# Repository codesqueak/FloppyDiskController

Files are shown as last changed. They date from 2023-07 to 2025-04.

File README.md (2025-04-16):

# Floppy Disk Controller Version 2.2.1

Nascom / Gemini / 80-Bus 1793 Floppy Disk Controller

## Introduction

This card has been designed to be a functional replacement for the Nascom Floppy Disk Controller.  It is fully compatible with the existing NAS-DOS software

The card is a completely new implementation of the design with a number of improvements over the original:

*	Completely new track layout
*	All components are readily available from commercial component suppliers (..and eBay!)
*	Switches are fitted to standard  DIL sockets
*	Copious test points
* Full documentation

For full documentation, see the [pdf here](FDC.pdf).

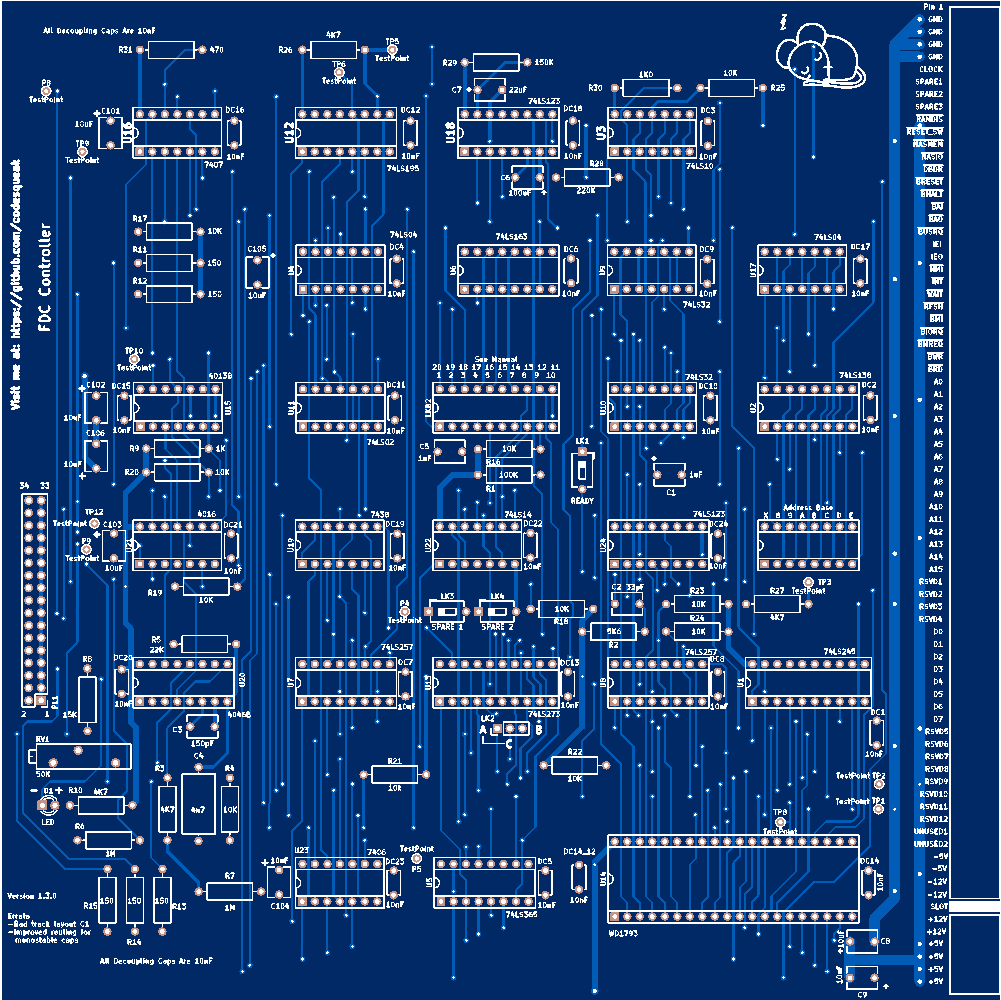
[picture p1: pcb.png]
PCB From JLCPCB
 

  Built PCB

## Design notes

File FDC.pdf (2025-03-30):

1793 Floppy Disk Controller Card

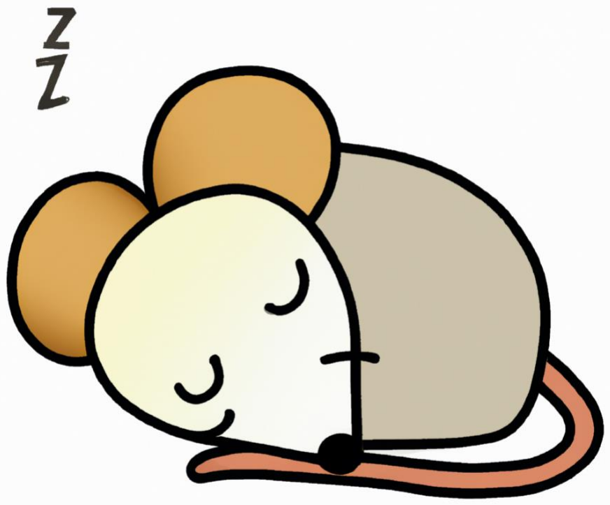
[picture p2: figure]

Issue 2.2.0 | Page 1 | 30-Mar-2025

## NAS-GEM-80 FDC CARD

### Instruction Manual & Functional Description

Issue 2.2.0 | Page 2 | 30-Mar-2025

## Contents

Issue 2.2.0 | Page 3 | 30-Mar-2025

## 1 Introduction

This card has been designed to be a form, fit and function replacement for the Nascom Floppy Disk

Controller, which is proving to be a very difficult item to source for the Nascom / Gemini retro

community.

The card has been tested against original Teac FD-50E/F drives without observed issues under NAS-

DOS 1.4

Further testing with CP/M and PolyDos is planned

Note: The card is designed to handle 5.25-inch drives. Support for 8-inch drives has been removed

(Did anyone ever use this?)

Issue 2.2.0 | Page 4 | 30-Mar-2025

## 2 Components

Reference | Value | Qty
C1 | 1uF | 1
C2 | 33pF | 1
C3 | 150pF | 1
C4 | 4n7 | 1
C5 | 1nF | 1
C6 | 100uF | 1
C7 | 22uF | 1
C8, C9, C101, C102, C103, C104, C105, C106 | 10uF | 8
D1 | LED | 1
DC1, DC2, DC3, DC4, DC5, DC6, DC7, DC8, DC9, DC10, DC11, DC12, DC13, DC14, DC14_12, DC15, DC16, DC17, DC18, DC19, DC20, DC21, DC22, DC23, DC24 | 10nF | 25
LK1 | READY | 1
LK2 | SW_SPDT | 1
LK3 | SPARE 1 | 1
LK4 | SPARE 2 | 1
LKB2 | Conn_02x10_Counter_Clockwise | 1
P4, P5, P8, P9, TP1, TP2, TP3, TP5, TP6, TP8, TP9, TP10, TP12 | Test Point | 13
PL1 | Conn_02x17_Odd_Even | 1
R1 | 100K | 1
R2 | 5K6 | 1
R3, R10, R26, R27 | 4K7 | 4
R4, R16, R17, R18, R19, R20, R22, R23, R24, R25 | 10K | 10
R5 | 22K | 1
R6, R7 | 1M | 2
R8 | 15K | 1
R9 | 1K | 1
R11, R12, R13, R14, R15 | 150 | 5
R21 | 10k | 1
R28 | 220K | 1
R29 | 150K | 1
R30 | 1K0 | 1
R31 | 470 | 1
RV1 | 50K | 1
SW1 | SW_DIP_x08 | 1
U1 | 74LS245 | 1
U2 | 74LS138 | 1
U3 | 74LS10 | 1
U4, U17 | 74LS04 | 2

Issue 2.2.0 | Page 5 | 30-Mar-2025
Reference | Value | Qty
U5 | 74LS365 | 1
U6 | 74LS163 | 1
U7, U8 | 74LS257 | 2
U9, U10 | 74LS32 | 2
U11 | 74LS02 | 1
U12 | 74LS195 | 1
U13 | 74LS273 | 1
U14 | WD1793 | 1
U15 | 4013B | 1
U16 | 7407 | 1
U18, U24 | 74LS123 | 2
U19 | 7438 | 1
U20 | 4046B | 1
U21 | 4016 | 1
U22 | 74LS14 | 1
U23 | 7406 | 1

Issue 2.2.0 | Page 6 | 30-Mar-2025

## 3 Construction

### 3.1 Before you start construction

Inspect the PCB for any visible signs of damage

Plug the board into an 80-BUS and power it up.

- Verify no latent shorts exist
- Verify correct voltages on power rails

Select your components:

- Turned pin sockets are recommended due to robustness and reliability
- Tantalum capacitors can be temperamental. Make sure they are inserted with the correct polarity, are of good quality and are overrated voltage wise.

U15, U20 & U21 are static sensitive. Handling precautions need to be observed.

### 3.2 Order of construction

The recommended order of construction is:

- Resistors
- Sockets
- Decoupling capacitors
- Tantalum capacitors
- Switches
- LED
- Wire header
- Insert IC’s

Issue 2.2.0 | Page 7 | 30-Mar-2025

## 4 Functionality

## 4.1 Links

The board contains 4 links, which can be implemented as switches or hard wired with links depending on the user’s preference.

Link (Default) Usage | Link (Default) Usage
LK1 Open Ready | LK1 Open Ready
LK2 A -> C | Side Select. Set A -> C for 1793 Side Select
LK3 Open | Spare – Port x4 Bit 5
LK4 Open | Spare – Port x4 Bit 7

## 4.2 SW1 – Base Port Select

This allows the board to be mapped to ports 0x20, 0x40, 0x60, 0x80, 0xA0, 0xC0, 0xE0. The default is 0xE0. User options are to either hard wire a link, use a link block or use an 8-way DIL switch

Connect Pins Port Base Address | Connect Pins Port Base Address
1 to 16 | N/A
2 to 15 | 0x20
3 to 14 | 0x40
4 to 13 | 0x60
5 to 12 | 0x80
6 to 11 | 0xA0
7 to 10 | 0xC0
8 to 9 (Default) | 0xE0

Issue 2.2.0 | Page 8 | 30-Mar-2025

## 4.3 LKB2 – Configuration Switch

This is implemented as a 10-way DIL switch. The switch settings are as follows:

Switch | Usage | 2MHz Default | 4MHz Default
SW1 | Set write pre-compensation | Off | Off
SW2 | Set write pre-compensation | Off | On
SW3 | Set write pre-compensation | Off | Off
SW4 | Clock divide by 2 (For 2MHz systems) | On | Off
SW5 | Clock divide by 4 (For 4MHz systems) | Off | On
SW6 | SW6 Clock divide by 4 (For 2MHz systems), | On | Off
SW7 | Clock divide by 8 (For 4MHz systems), VCO=500KHz | Off | On
SW8 | Select single /. double density | On | On
SW9 | Disable / enable track 43 pre-compensation | On | On
SW0 | Disable write pre-compensation | On | Off

Notes on write pre-compensation:

For 2MHz systems, SW1 is set to on, giving 500ns pre-compensation

For 4MHz systems, SW2 is set to one giving 250ns pre-compensation OR SW3 is set to on giving 500ns pre-compensation

Only one of SW1, SW2 or SW3 should be selected at any time. If all are deselected then SW0 must be selected (disables write pre-compensation)

## 4.4 Ports

The board uses six ports, selected from the base port (Default 0xE0). These are:

Port | Read | Write
0xE0 | 1793 Status | 1793 Command register
0xE1 | 1793 Track | 1793 Track register
0xE2 | 1793 Sector | 1793 Sector Register
0xE3 | 1793 Data | 1793 Data register
0xE4 | Drive | Drive select control
0xE5 | INTRQ / DRQ status | N/A

Issue 2.2.0 | Page 9 | 30-Mar-2025

### 4.4.1 For Port 0xE4

Bit | Read | Write
0 | Drive select 0 | Drive select 0
1 | Drive select 1 | Drive select 1
2 | Drive select 2 | Drive select 2
3 | Drive select 3 | Drive select 3
4 | Side select | Side select (When LK2 A->C)
5 | LK3 | Motor 0=off, 1=on
6 | Density (0=low, 1 = high) | Density (0=low, 1 = high)
7 | LK4 | N/A

### 4.4.2 For Port 0xE5

Bit | Read | Write
0 | 1793 INTRQ | N/A
1 | 0=Ready, 1=Not Ready | N/A
2 | N/A | N/A
3 | N/A | N/A
4 | N/A | N/A
5 | N/A | N/A
6 | N/A | N/A
7 | 1793 DRQ | N/A

Issue 2.2.0 | Page 10 | 30-Mar-2025

## 5 Configuration

Once the board has been built and configured via links options and switches, the VCO center

frequency needs to be set. This can be done in two ways:

## 5.1 Without A Scope

The following steps are required to perform the configuration:

1. Ensure the board is disconnected from any drives (Disconnect PL1)
2. Turn the potentiometer at VR1 anti-clockwise until the LED illuminates
3. Turn the potentiometer at VR1 a quarter turn clockwise

## 5.2 With A Scope

The following steps are required to perform the configuration:

1. Ensure the board is disconnected from any drives (Disconnect PL1)
2. Observe the signal at U20 Pin 3
3. Turn the potentiometer until a 500KHz square wave is observed

Issue 2.2.0 | Page 11 | 30-Mar-2025

## 6 Notes on Components

All the components used have been selected at time of design to be readily available via eBay and

other sources.

## 6.1 LKB2 Configuration Switch

It is recommended to fit a 20-pin socket and use a 10-way DIL switch

## 6.2 SW1 Decode Header

The socket at SW1 is recommended to be of the turned pin variety so as to allow easier insertion of

the header. The default header is a 16-way DIL header.

An alternative is to use Single-In-Line (SIL) Turned Pin Socket 0.1 Inch Pitch strips which are readily

available instead of a header. These are then snipped down to the required number of pins before

being inserted into the socket and the desired wire links being made. An 8-way DIL switch may also

be used if one is available.

A second alternative is to insert and solder a wire link between the required PCB pads if the ability to

change the base address is not required.
6.3 C4

This capacitor is of the film type in the original design. I have used an Axial Polypropylene Film

Capacitor here without issue. Other types (e.g. ceramic) may work but that configuration is untested.

## 6.4 IC’s U15, U20, U21

These parts are static sensitive. Handling precautions need to be observed.

## 6.5 1793 FDC Controller

A 1797 controller, in theory, may be substituted, but this configuration is untested. To use the 1797

Side-Select feature, set LK3 to B -> C

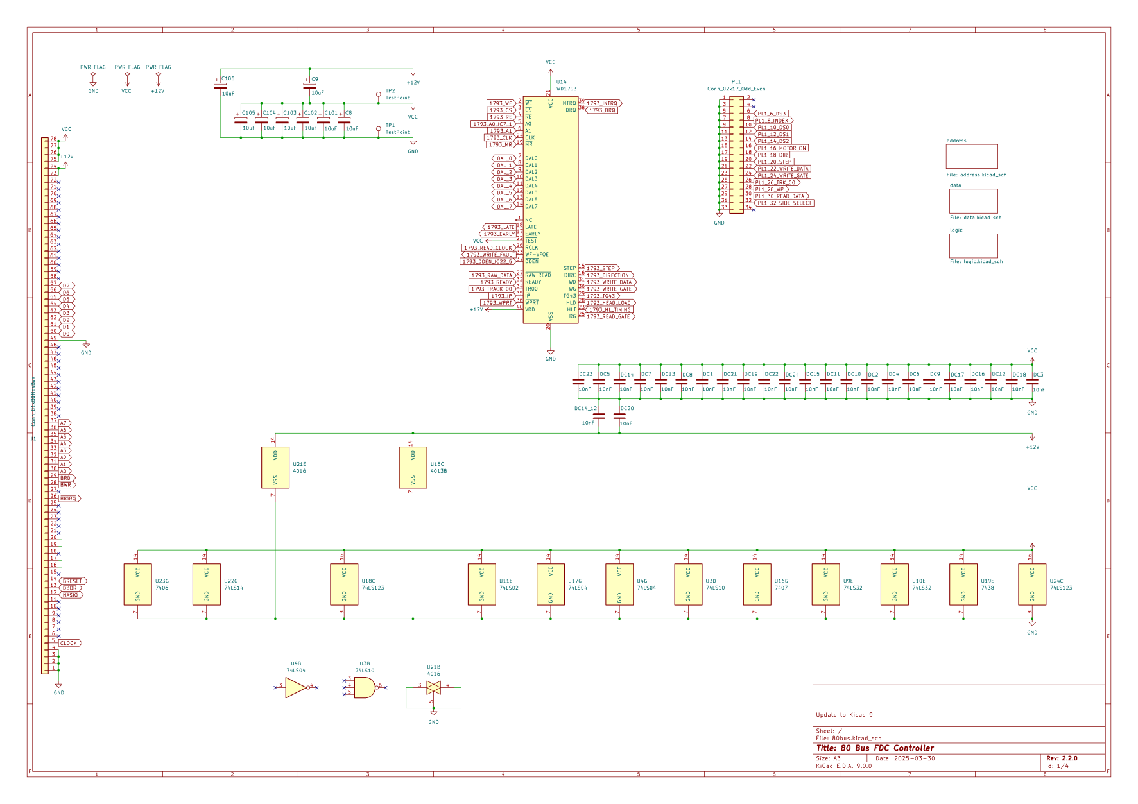
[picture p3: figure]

Issue 2.2.0 | Page 12 | 30-Mar-2025

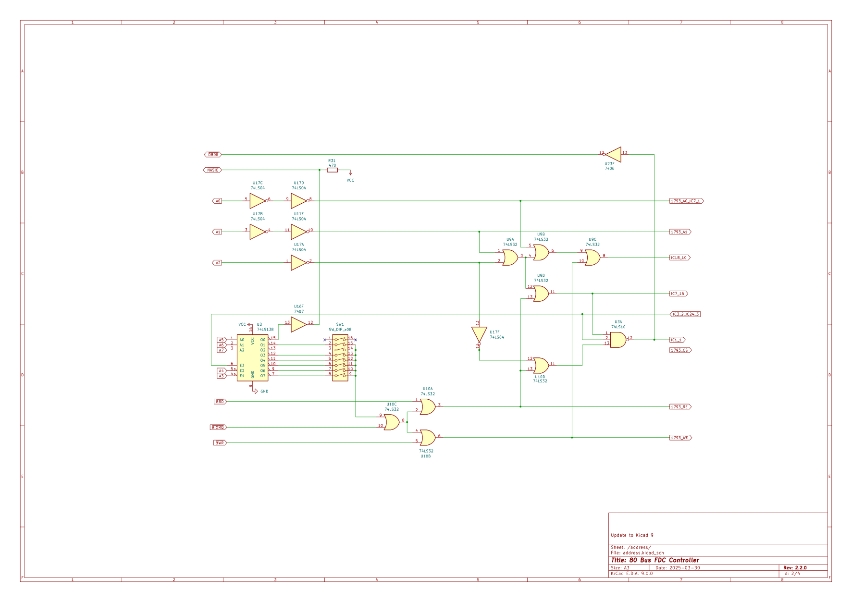
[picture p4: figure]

Issue 2.2.0 | Page 13 | 30-Mar-2025

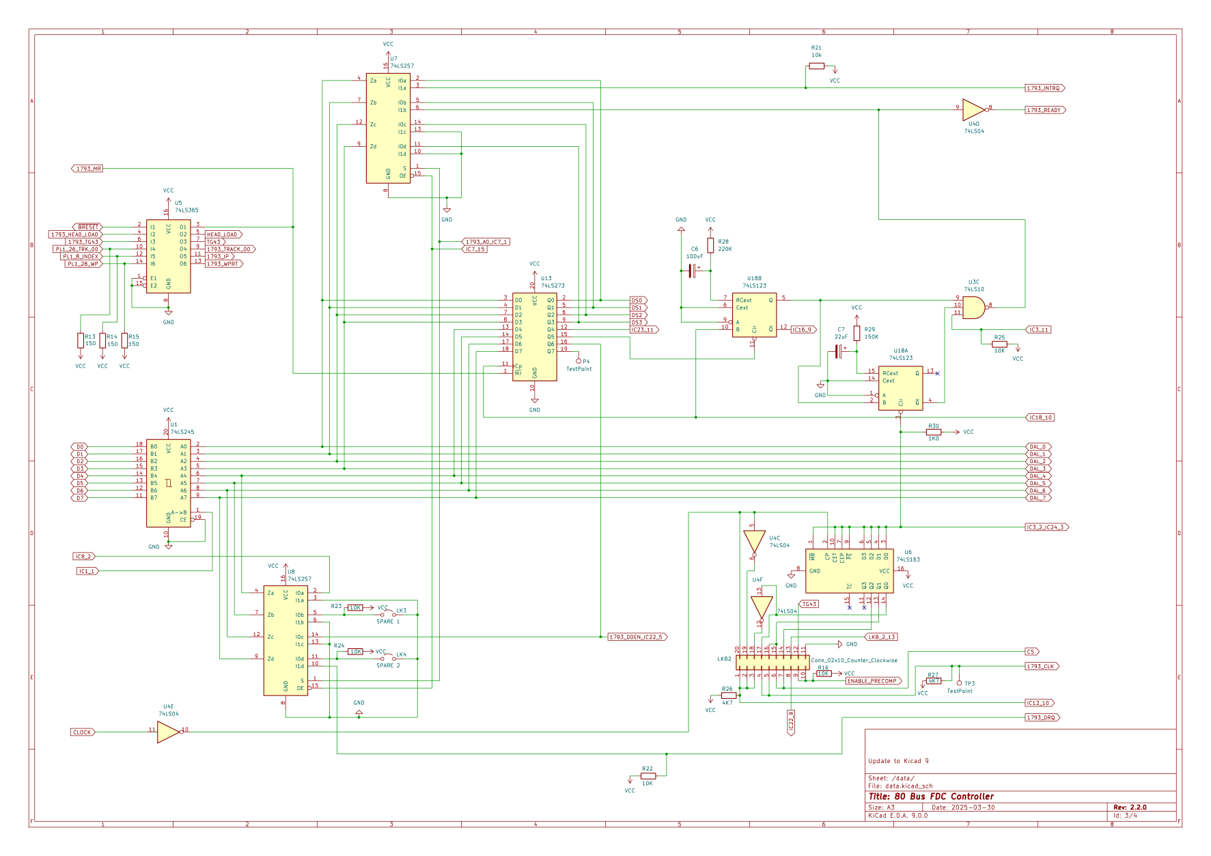
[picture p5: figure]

Issue 2.2.0 | Page 14 | 30-Mar-2025

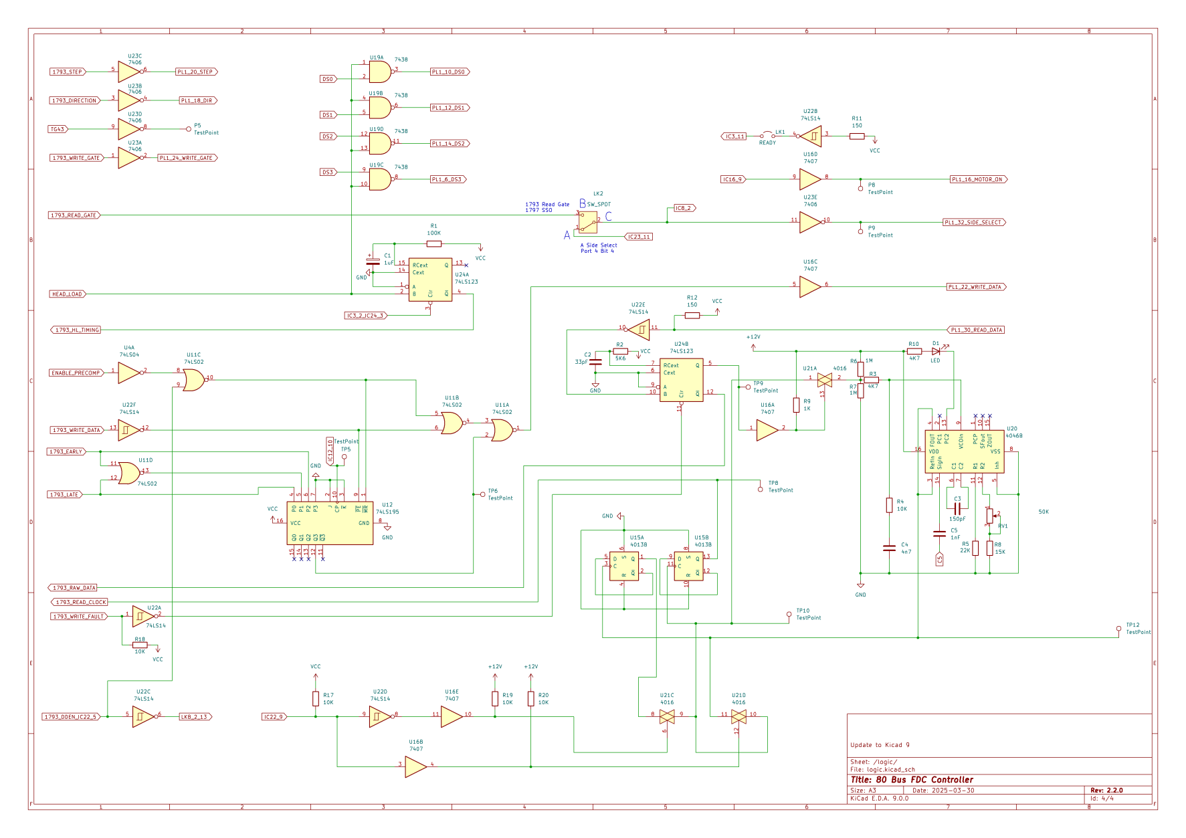
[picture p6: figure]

Issue 2.2.0 | Page 15 | 30-Mar-2025

Issue 2.2.0 | Page 16 | 30-Mar-2025

Issue 2.2.0 | Page 17 | 30-Mar-2025

## 7 Errata

Initial release boards (1.2.0) have an incorrect ground line for C1.

The capacitor at location C1 should be:

1. Mounted on the back of the board
2. The positive leg should go through the existing positive through plated hole for the component
3. The negative leg should go to pin 14 of U24

This modification fixes an issue with the unstable operation of the Head Load monostable

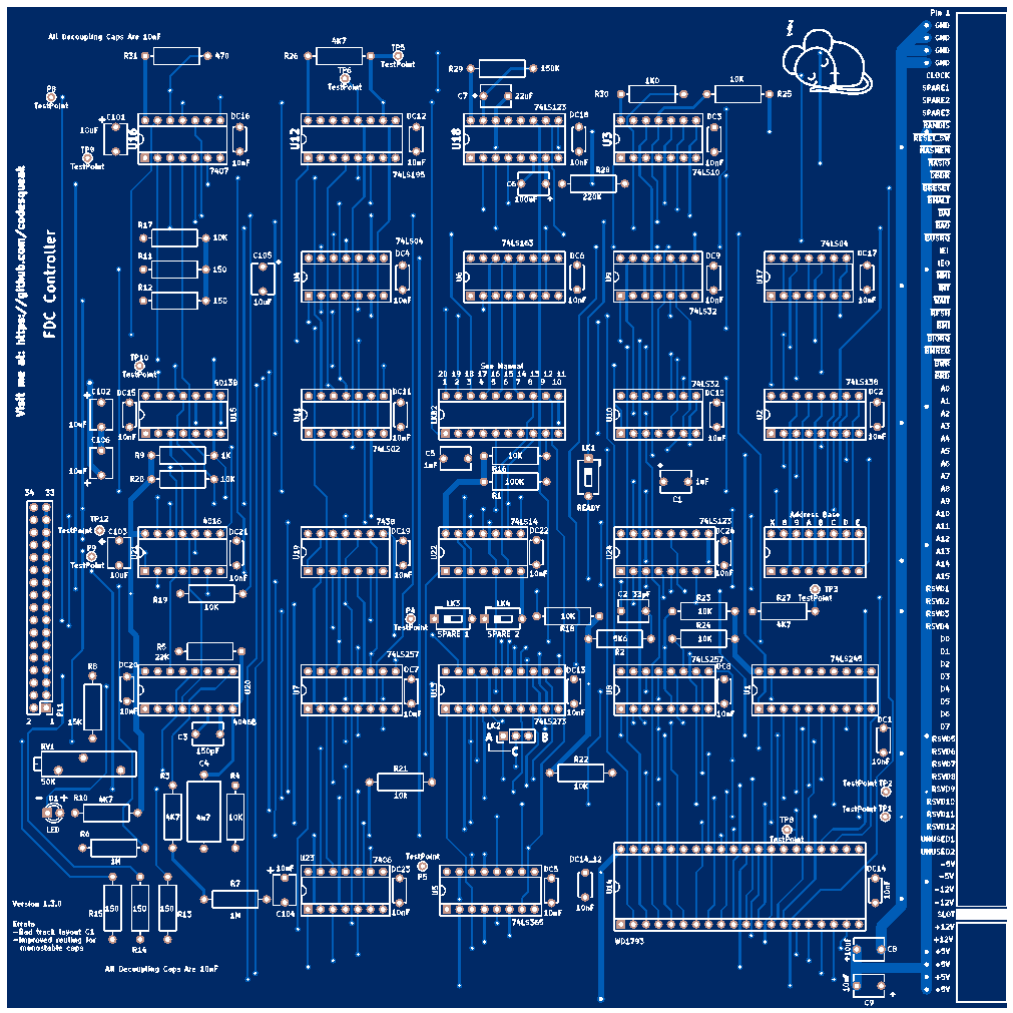
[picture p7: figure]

Issue 2.2.0 | Page 18 | 30-Mar-2025

## 8 Reference Images

### 8.1 PCB

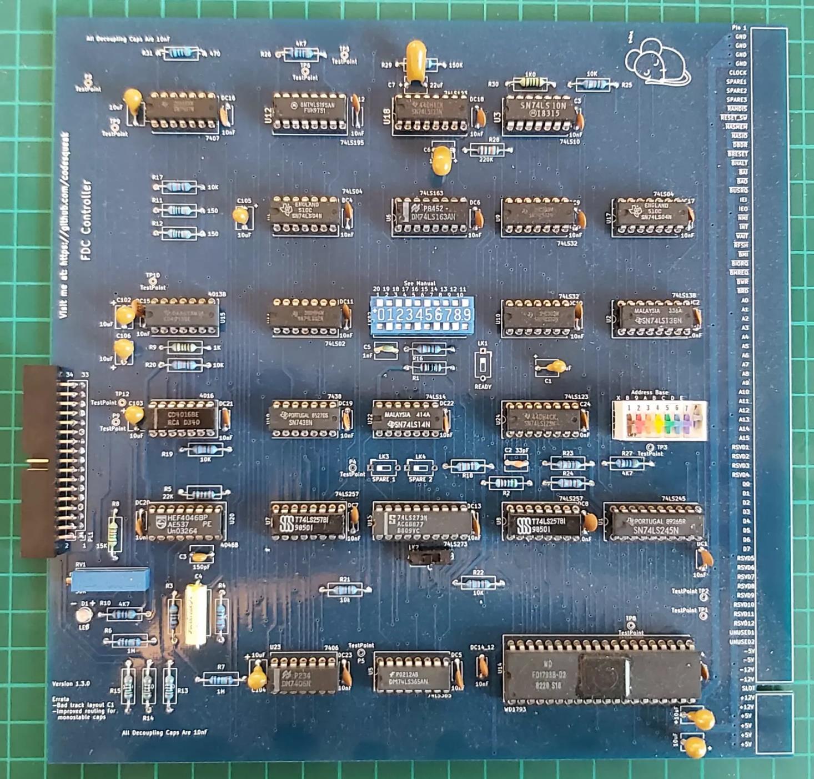
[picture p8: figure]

Issue 2.2.0 | Page 19 | 30-Mar-2025

### 8.2 Built

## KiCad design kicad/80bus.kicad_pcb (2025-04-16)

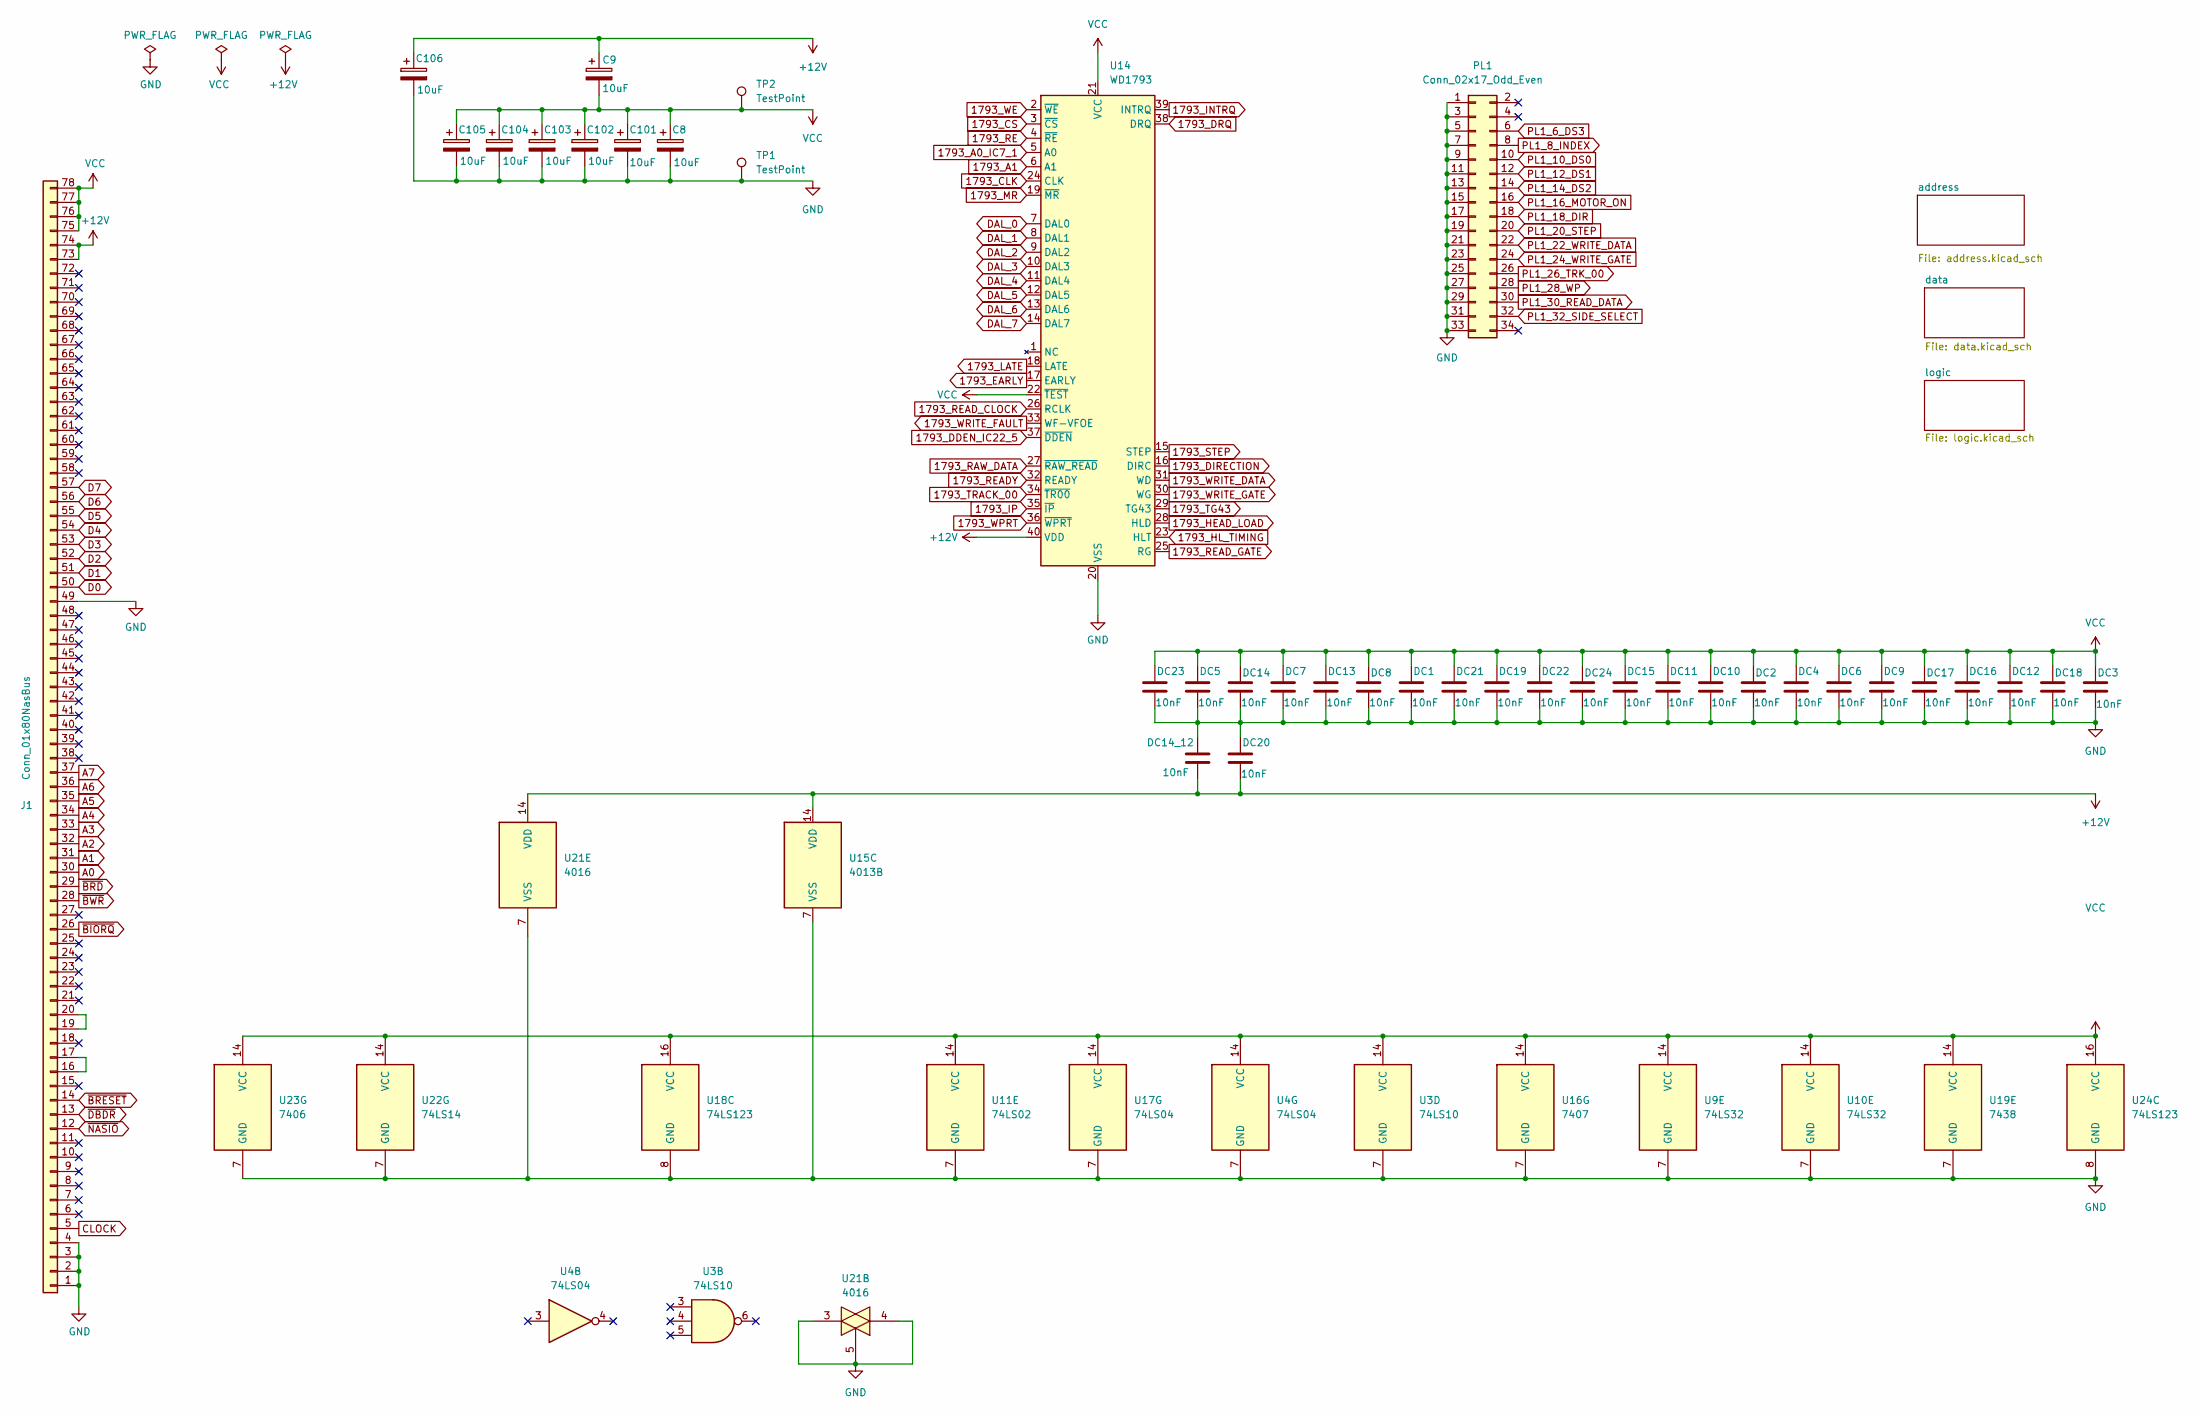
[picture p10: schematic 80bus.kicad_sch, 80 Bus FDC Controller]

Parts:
C8, C9, C101, C102, C103, C104, C105, C106: 10uF; C_Disc_D6.0mm_W4.4mm_P5.00mm
DC1, DC2, DC3, DC4, DC5, DC6, DC7, DC8, DC9, DC10, DC11, DC12, DC13, DC14, DC14_12, DC15, DC16, DC17, DC18, DC19, DC20, DC21, DC22, DC23, DC24: 10nF; C_Disc_D4.7mm_W2.5mm_P5.00mm
J1: Conn_01x80NasBus; 80BusEdgeConnector
PL1: Conn_02x17_Odd_Even; PinHeader_2x17_P2.54mm_Vertical
TP1, TP2: TestPoint; TestPoint_THTPad_D1.5mm_Drill0.7mm
U3: 74LS10; DIP-14_W7.62mm_Socket
U4, U17: 74LS04; DIP-14_W7.62mm_Socket
U9, U10: 74LS32; DIP-14_W7.62mm_Socket
U11: 74LS02; DIP-14_W7.62mm_Socket
U14: WD1793; DIP-40_W15.24mm
U15: 4013B; DIP-14_W7.62mm_Socket
U16: 7407; DIP-14_W7.62mm_Socket
U18, U24: 74LS123; DIP-16_W7.62mm_Socket
U19: 7438; DIP-14_W7.62mm_Socket
U21: 4016; DIP-14_W7.62mm_Socket
U22: 74LS14; DIP-14_W7.62mm_Socket
U23: 7406; DIP-14_W7.62mm_Socket

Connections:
1793_A0_IC7_1: U14.5 (A0); also elsewhere on the board
1793_A1: U14.6 (A1); also elsewhere on the board
1793_CLK: U14.24 (CLK); also elsewhere on the board
1793_CS: U14.3 (~CS); also elsewhere on the board
1793_DDEN_IC22_5: U14.37 (~DDEN); also elsewhere on the board
1793_DIRECTION: U14.16 (DIRC); also elsewhere on the board
1793_DRQ: U14.38 (DRQ); also elsewhere on the board
1793_EARLY: U14.17 (EARLY); also elsewhere on the board
1793_HEAD_LOAD: U14.28 (HLD); also elsewhere on the board
1793_HL_TIMING: U14.23 (HLT); also elsewhere on the board
1793_INTRQ: U14.39 (INTRQ); also elsewhere on the board
1793_IP: U14.35 (~IP); also elsewhere on the board
1793_LATE: U14.18 (LATE); also elsewhere on the board
1793_MR: U14.19 (~MR); also elsewhere on the board
1793_RAW_DATA: U14.27 (~RAW_READ); also elsewhere on the board
1793_RE: U14.4 (~RE); also elsewhere on the board
1793_READY: U14.32 (READY); also elsewhere on the board
1793_READ_CLOCK: U14.26 (RCLK); also elsewhere on the board
1793_READ_GATE: U14.25 (RG); also elsewhere on the board
1793_STEP: U14.15 (STEP); also elsewhere on the board
1793_TG43: U14.29 (TG43); also elsewhere on the board
1793_TRACK_00: U14.34 (~TR00); also elsewhere on the board
1793_WE: U14.2 (~WE); also elsewhere on the board
1793_WPRT: U14.36 (~WPRT); also elsewhere on the board
1793_WRITE_DATA: U14.31 (WD); also elsewhere on the board
1793_WRITE_FAULT: U14.33 (WF-VFOE); also elsewhere on the board
1793_WRITE_GATE: U14.30 (WG); also elsewhere on the board
+12V: C9.1, C106.1, DC14_12.2, DC20.2, J1.73 (Pin_73_+12v), J1.74 (Pin_74_+12v), U14.40 (VDD), U15.14 (VDD), U21.14 (VDD); also elsewhere on the board
A0: J1.30; also elsewhere on the board
A1: J1.31; also elsewhere on the board
A2: J1.32; also elsewhere on the board
A3: J1.33; also elsewhere on the board
A4: J1.34; also elsewhere on the board
A5: J1.35; also elsewhere on the board
A6: J1.36; also elsewhere on the board
A7: J1.37; also elsewhere on the board
CLOCK: J1.5; also elsewhere on the board
D0: J1.50; also elsewhere on the board
D1: J1.51; also elsewhere on the board
D2: J1.52; also elsewhere on the board
D3: J1.53; also elsewhere on the board
D4: J1.54; also elsewhere on the board
D5: J1.55; also elsewhere on the board
D6: J1.56; also elsewhere on the board
D7: J1.57; also elsewhere on the board
DAL_0: U14.7 (DAL0); also elsewhere on the board
DAL_1: U14.8 (DAL1); also elsewhere on the board
DAL_2: U14.9 (DAL2); also elsewhere on the board
DAL_3: U14.10 (DAL3); also elsewhere on the board
DAL_4: U14.11 (DAL4); also elsewhere on the board
DAL_5: U14.12 (DAL5); also elsewhere on the board
DAL_6: U14.13 (DAL6); also elsewhere on the board
DAL_7: U14.14 (DAL7); also elsewhere on the board
GND: C8.2, C101.2, C102.2, C103.2, C104.2, C105.2, C106.2, DC1.2, DC2.2, DC3.2, DC4.2, DC5.2, DC6.2, DC7.2, DC8.2, DC9.2, DC10.2, DC11.2, DC12.2, DC13.2, DC14.2, DC14_12.1, DC15.2, DC16.2, DC17.2, DC18.2, DC19.2, DC20.1, DC21.2, DC22.2, DC23.2, DC24.2, J1.1 (Pin_1_0v), J1.2 (Pin_2_0v), J1.3 (Pin_3_0v), J1.4 (Pin_4_0v), J1.49, PL1.1, PL1.3, PL1.5, PL1.7, PL1.9, PL1.11, PL1.13, PL1.15, PL1.17, PL1.19, PL1.21, PL1.23, PL1.25, PL1.27, PL1.29, PL1.31, PL1.33, TP1.1, U3.7 (GND), U4.7 (GND), U9.7 (GND), U10.7 (GND), U11.7 (GND), U14.20 (VSS), U15.7 (VSS), U16.7 (GND), U17.7 (GND), U18.8 (GND), U19.7 (GND), U21.3, U21.4, U21.5, U21.7 (VSS), U22.7 (GND), U23.7 (GND), U24.8 (GND); also elsewhere on the board
unnamed: J1.16, J1.17
unnamed: J1.19, J1.20
PL1_6_DS3: PL1.6; also elsewhere on the board
PL1_8_INDEX: PL1.8; also elsewhere on the board
PL1_10_DS0: PL1.10; also elsewhere on the board
PL1_12_DS1: PL1.12; also elsewhere on the board
PL1_14_DS2: PL1.14; also elsewhere on the board
PL1_16_MOTOR_ON: PL1.16; also elsewhere on the board
PL1_18_DIR: PL1.18; also elsewhere on the board
PL1_20_STEP: PL1.20; also elsewhere on the board
PL1_22_WRITE_DATA: PL1.22; also elsewhere on the board
PL1_24_WRITE_GATE: PL1.24; also elsewhere on the board
PL1_26_TRK_00: PL1.26; also elsewhere on the board
PL1_28_WP: PL1.28; also elsewhere on the board
PL1_30_READ_DATA: PL1.30; also elsewhere on the board
PL1_32_SIDE_SELECT: PL1.32; also elsewhere on the board
VCC: C8.1, C9.2, C101.1, C102.1, C103.1, C104.1, C105.1, DC1.1, DC2.1, DC3.1, DC4.1, DC5.1, DC6.1, DC7.1, DC8.1, DC9.1, DC10.1, DC11.1, DC12.1, DC13.1, DC14.1, DC15.1, DC16.1, DC17.1, DC18.1, DC19.1, DC21.1, DC22.1, DC23.1, DC24.1, J1.75 (Pin_75_+5v), J1.76 (Pin_76_+5v), J1.77 (Pin_77__+5v), J1.78 (Pin_78__+5v), TP2.1, U3.14 (VCC), U4.14 (VCC), U9.14 (VCC), U10.14 (VCC), U11.14 (VCC), U14.21 (VCC), U14.22 (~TEST), U16.14 (VCC), U17.14 (VCC), U18.16 (VCC), U19.14 (VCC), U22.14 (VCC), U23.14 (VCC), U24.16 (VCC); also elsewhere on the board
~BIORQ: J1.26; also elsewhere on the board
~BRD: J1.29; also elsewhere on the board
~BRESET: J1.14; also elsewhere on the board
~BWR: J1.28; also elsewhere on the board
~DBDR: J1.13; also elsewhere on the board
~NASIO: J1.12; also elsewhere on the board

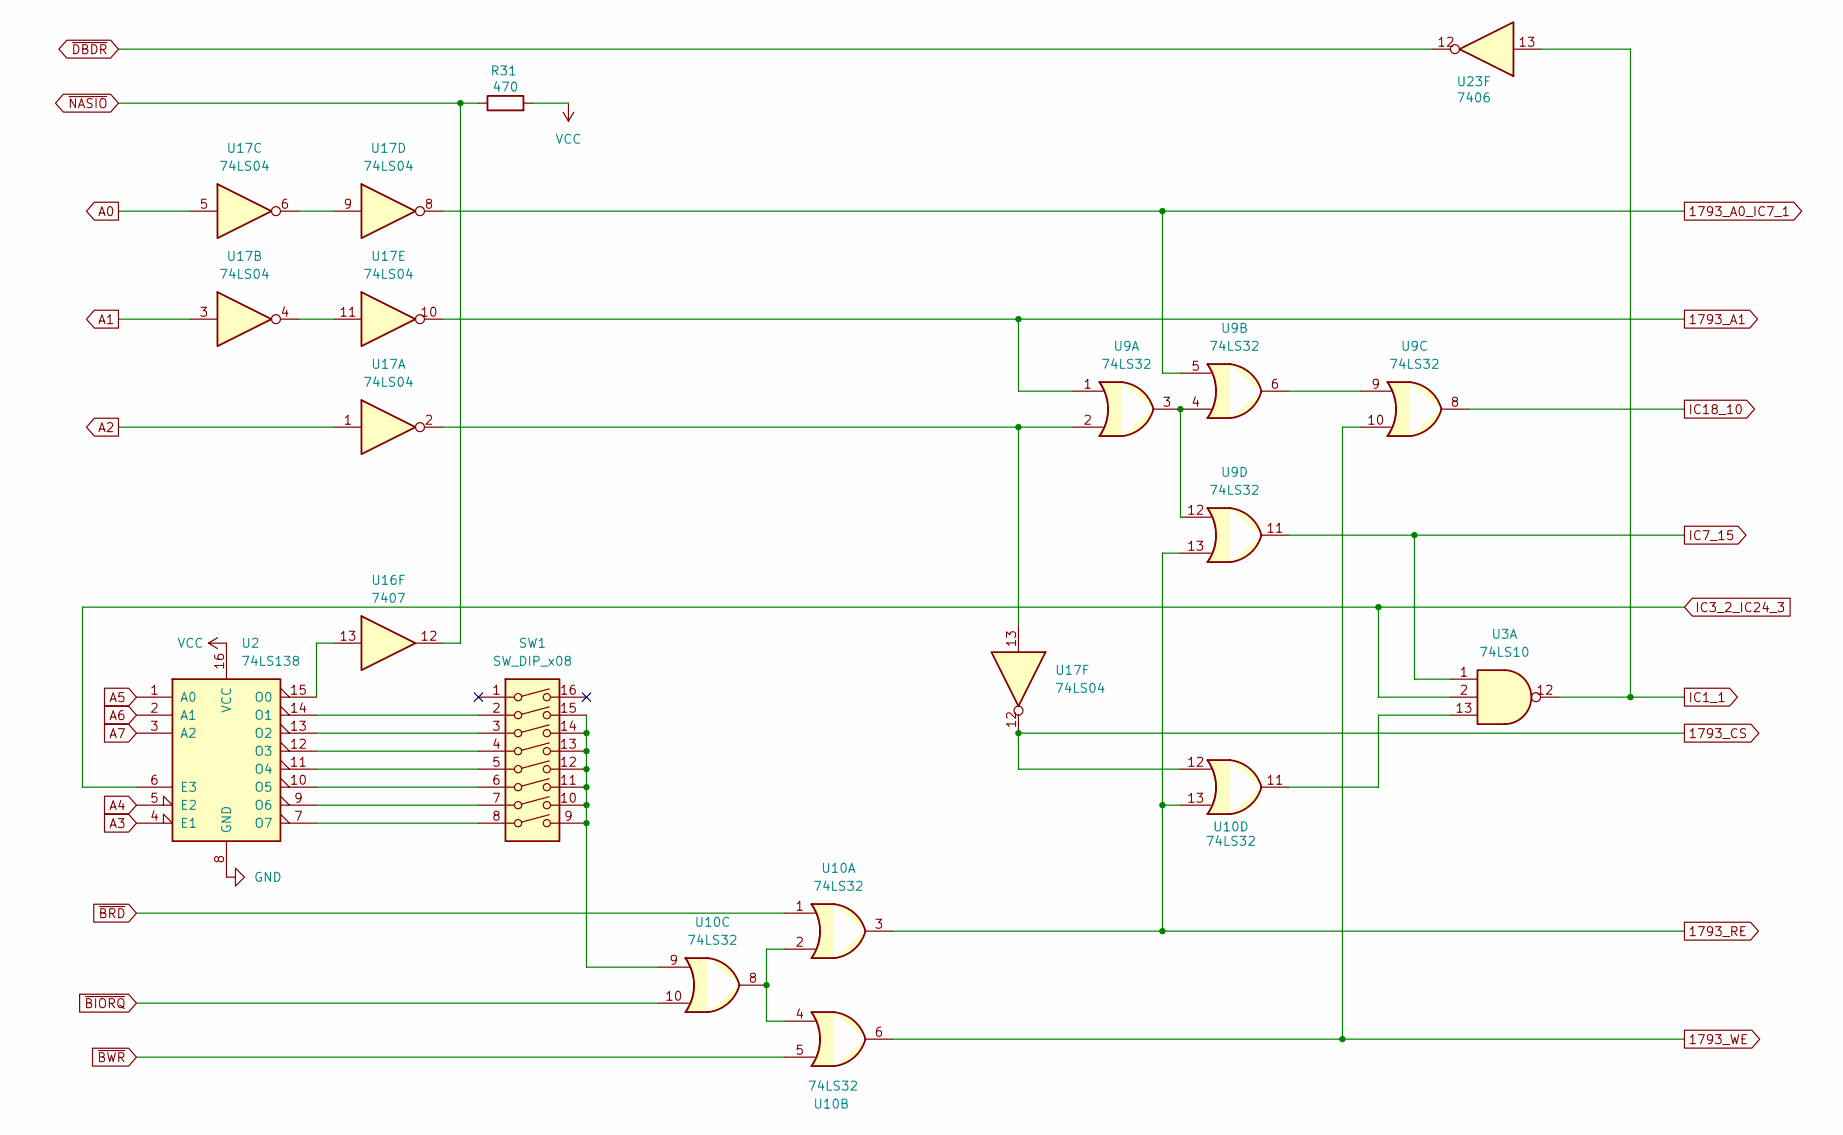
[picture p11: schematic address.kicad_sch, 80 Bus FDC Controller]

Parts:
R31: 470; R_Axial_DIN0309_L9.0mm_D3.2mm_P12.70mm_Horizontal
SW1: SW_DIP_x08; DIP-16_W7.62mm_Socket
U2: 74LS138; DIP-16_W7.62mm_Socket
U3: 74LS10; DIP-14_W7.62mm_Socket
U9, U10: 74LS32; DIP-14_W7.62mm_Socket
U16: 7407; DIP-14_W7.62mm_Socket
U17: 74LS04; DIP-14_W7.62mm_Socket
U23: 7406; DIP-14_W7.62mm_Socket

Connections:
1793_A0_IC7_1: U9.5, U17.8; also elsewhere on the board
1793_A1: U9.1, U17.10; also elsewhere on the board
1793_CS: U10.12, U17.12; also elsewhere on the board
1793_RE: U9.13, U10.3, U10.13; also elsewhere on the board
1793_WE: U9.10, U10.6; also elsewhere on the board
A0: U17.5; also elsewhere on the board
A1: U17.3; also elsewhere on the board
A2: U17.1; also elsewhere on the board
A3: U2.4 (E1); also elsewhere on the board
A4: U2.5 (E2); also elsewhere on the board
A5: U2.1 (A0); also elsewhere on the board
A6: U2.2 (A1); also elsewhere on the board
A7: U2.3 (A2); also elsewhere on the board
GND: U2.8 (GND); also elsewhere on the board
IC1_1: U3.12, U23.13; also elsewhere on the board
IC3_2_IC24_3: U2.6 (E3), U3.2; also elsewhere on the board
IC7_15: U3.1, U9.11; also elsewhere on the board
IC18_10: U9.8; also elsewhere on the board
unnamed: SW1.9, SW1.10, SW1.11, SW1.12, SW1.13, SW1.14, SW1.15, U10.9
unnamed: U2.15 (O0), U16.13
unnamed: SW1.2, U2.14 (O1)
unnamed: SW1.3, U2.13 (O2)
unnamed: SW1.4, U2.12 (O3)
unnamed: SW1.5, U2.11 (O4)
unnamed: SW1.6, U2.10 (O5)
unnamed: SW1.7, U2.9 (O6)
unnamed: SW1.8, U2.7 (O7)
unnamed: U9.6, U9.9
unnamed: U9.3, U9.4, U9.12
unnamed: U10.2, U10.4, U10.8
unnamed: U3.13, U10.11
unnamed: U17.6, U17.9
unnamed: U17.4, U17.11
unnamed: U9.2, U17.2, U17.13
VCC: R31.2, U2.16 (VCC); also elsewhere on the board
~BIORQ: U10.10; also elsewhere on the board
~BRD: U10.1; also elsewhere on the board
~BWR: U10.5; also elsewhere on the board
~DBDR: U23.12; also elsewhere on the board
~NASIO: R31.1, U16.12; also elsewhere on the board

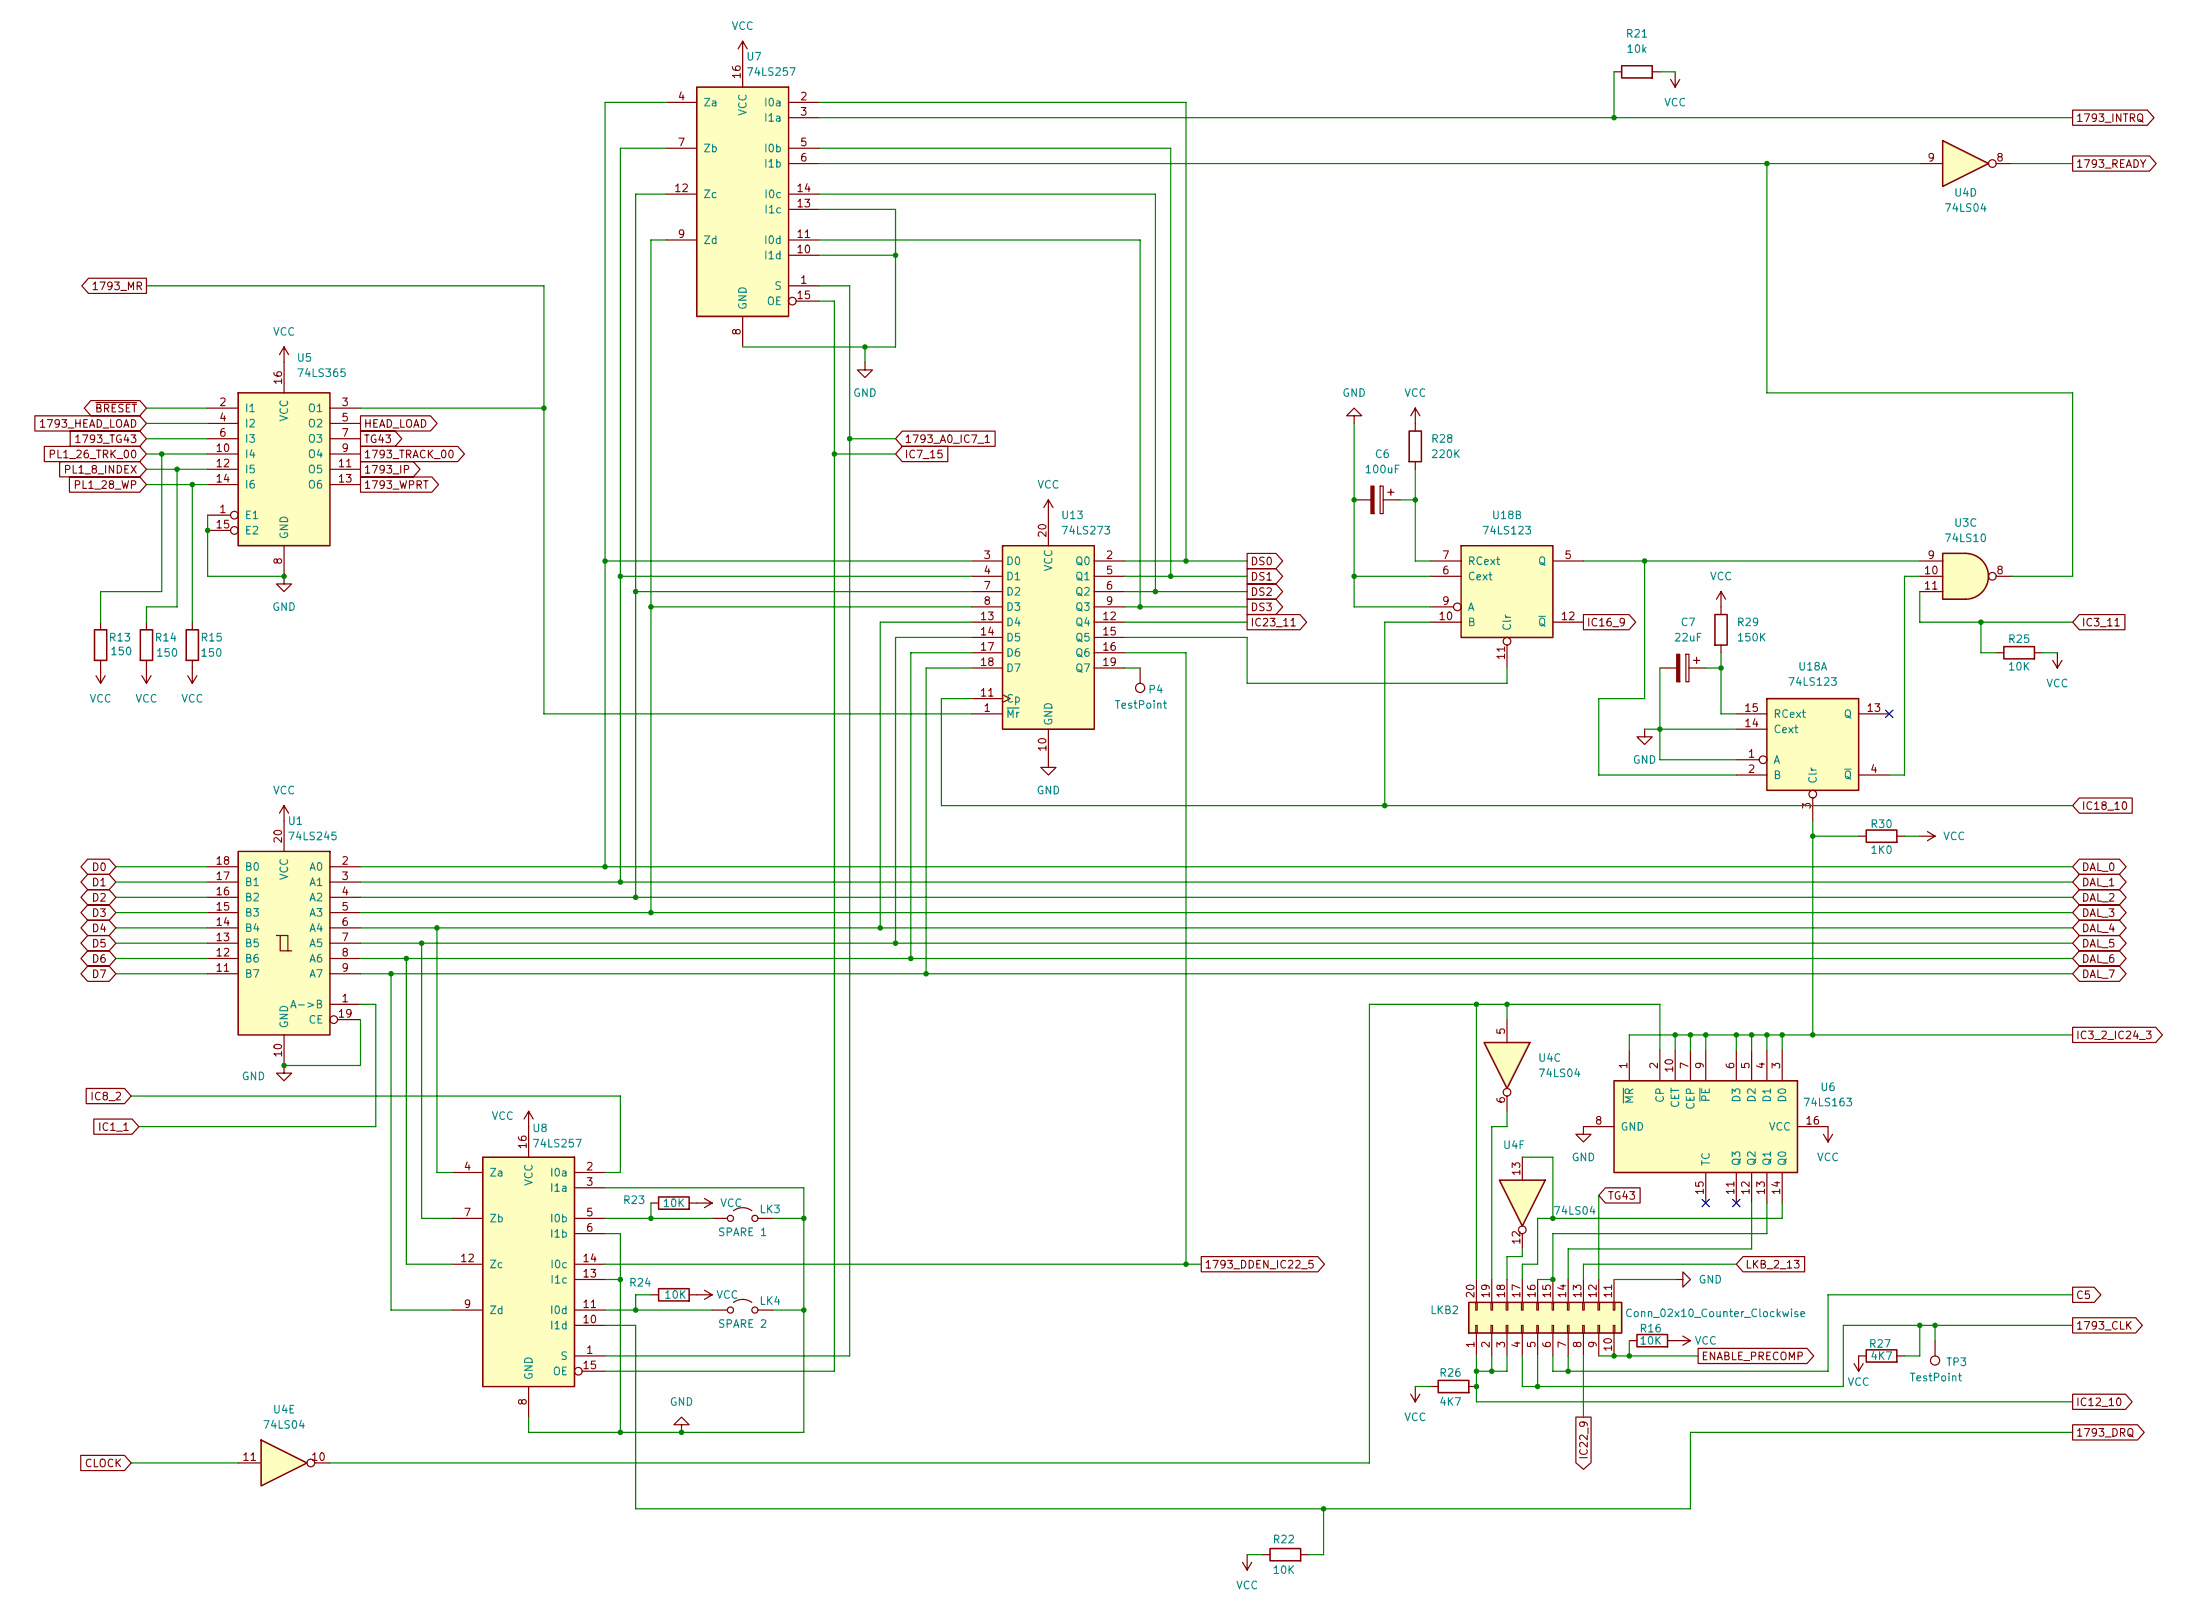
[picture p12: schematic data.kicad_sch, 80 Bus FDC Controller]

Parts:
C6: 100uF; C_Disc_D6.0mm_W4.4mm_P5.00mm
C7: 22uF; C_Disc_D6.0mm_W4.4mm_P5.00mm
LK3: SPARE 1; SW_DIP_SPSTx01_Slide_6.7x4.1mm_W7.62mm_P2.54mm_LowProfile
LK4: SPARE 2; SW_DIP_SPSTx01_Slide_6.7x4.1mm_W7.62mm_P2.54mm_LowProfile
LKB2: Conn_02x10_Counter_Clockwise; DIP-20_W7.62mm_Socket
P4: TestPoint; TestPoint_THTPad_D1.5mm_Drill0.7mm
R13, R14, R15: 150; R_Axial_DIN0309_L9.0mm_D3.2mm_P12.70mm_Horizontal
R16, R22, R23, R24, R25: 10K; R_Axial_DIN0309_L9.0mm_D3.2mm_P12.70mm_Horizontal
R21: 10k; R_Axial_DIN0309_L9.0mm_D3.2mm_P12.70mm_Horizontal
R26, R27: 4K7; R_Axial_DIN0309_L9.0mm_D3.2mm_P12.70mm_Horizontal
R28: 220K; R_Axial_DIN0309_L9.0mm_D3.2mm_P12.70mm_Horizontal
R29: 150K; R_Axial_DIN0309_L9.0mm_D3.2mm_P12.70mm_Horizontal
R30: 1K0; R_Axial_DIN0309_L9.0mm_D3.2mm_P12.70mm_Horizontal
TP3: TestPoint; TestPoint_THTPad_D1.5mm_Drill0.7mm
U1: 74LS245; DIP-20_W7.62mm_Socket
U3: 74LS10; DIP-14_W7.62mm_Socket
U4: 74LS04; DIP-14_W7.62mm_Socket
U5: 74LS365; DIP-16_W7.62mm_Socket
U6: 74LS163; DIP-16_W7.62mm_Socket
U7, U8: 74LS257; DIP-16_W7.62mm_Socket
U13: 74LS273; DIP-20_W7.62mm_Socket
U18: 74LS123; DIP-16_W7.62mm_Socket

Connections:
1793_A0_IC7_1: U7.1 (S), U8.1 (S); also elsewhere on the board
1793_CLK: LKB2.4, LKB2.5, R27.2, TP3.1; also elsewhere on the board
1793_DDEN_IC22_5: U8.14 (I0c), U13.16 (Q6); also elsewhere on the board
1793_DRQ: R22.2, U8.10 (I1d); also elsewhere on the board
1793_HEAD_LOAD: U5.4 (I2); also elsewhere on the board
1793_INTRQ: R21.1, U7.3 (I1a); also elsewhere on the board
1793_IP: U5.11 (O5); also elsewhere on the board
1793_MR: U5.3 (O1), U13.1 (~Mr); also elsewhere on the board
1793_READY: U4.8; also elsewhere on the board
1793_TG43: U5.6 (I3); also elsewhere on the board
1793_TRACK_00: U5.9 (O4); also elsewhere on the board
1793_WPRT: U5.13 (O6); also elsewhere on the board
C5: LKB2.6, LKB2.7; also elsewhere on the board
CLOCK: U4.11; also elsewhere on the board
D0: U1.18 (B0); also elsewhere on the board
D1: U1.17 (B1); also elsewhere on the board
D2: U1.16 (B2); also elsewhere on the board
D3: U1.15 (B3); also elsewhere on the board
D4: U1.14 (B4); also elsewhere on the board
D5: U1.13 (B5); also elsewhere on the board
D6: U1.12 (B6); also elsewhere on the board
D7: U1.11 (B7); also elsewhere on the board
DAL_0: U1.2 (A0), U7.4 (Za), U13.3 (D0); also elsewhere on the board
DAL_1: U1.3 (A1), U7.7 (Zb), U13.4 (D1); also elsewhere on the board
DAL_2: U1.4 (A2), U7.12 (Zc), U13.7 (D2); also elsewhere on the board
DAL_3: U1.5 (A3), U7.9 (Zd), U13.8 (D3); also elsewhere on the board
DAL_4: U1.6 (A4), U8.4 (Za), U13.13 (D4); also elsewhere on the board
DAL_5: U1.7 (A5), U8.7 (Zb), U13.14 (D5); also elsewhere on the board
DAL_6: U1.8 (A6), U8.12 (Zc), U13.17 (D6); also elsewhere on the board
DAL_7: U1.9 (A7), U8.9 (Zd), U13.18 (D7); also elsewhere on the board
DS0: U7.2 (I0a), U13.2 (Q0); also elsewhere on the board
DS1: U7.5 (I0b), U13.5 (Q1); also elsewhere on the board
DS2: U7.14 (I0c), U13.6 (Q2); also elsewhere on the board
DS3: U7.11 (I0d), U13.9 (Q3); also elsewhere on the board
ENABLE_PRECOMP: LKB2.9, LKB2.10, R16.1; also elsewhere on the board
GND: C6.2, C7.2, LK3.2 (B), LK4.2 (B), LKB2.11, U1.10 (GND), U1.19 (CE), U5.1 (E1), U5.8 (GND), U5.15 (E2), U6.8 (GND), U7.8 (GND), U7.10 (I1d), U7.13 (I1c), U8.3 (I1a), U8.6 (I1b), U8.8 (GND), U8.13 (I1c), U13.10 (GND), U18.1 (A), U18.6 (Cext), U18.9 (A), U18.14 (Cext); also elsewhere on the board
HEAD_LOAD: U5.5 (O2); also elsewhere on the board
IC1_1: U1.1 (A->B); also elsewhere on the board
IC3_2_IC24_3: R30.1, U6.1 (~MR), U6.3 (D0), U6.4 (D1), U6.5 (D2), U6.6 (D3), U6.7 (CEP), U6.9 (~PE), U6.10 (CET), U18.3 (Clr); also elsewhere on the board
IC3_11: R25.1, U3.11; also elsewhere on the board
IC7_15: U7.15 (OE), U8.15 (OE); also elsewhere on the board
IC8_2: U8.2 (I0a); also elsewhere on the board
IC12_10: LKB2.1, LKB2.2, LKB2.3, R26.2; also elsewhere on the board
IC16_9: U18.12 (~Q); also elsewhere on the board
IC18_10: U13.11 (Cp), U18.10 (B); also elsewhere on the board
IC22_9: LKB2.8; also elsewhere on the board
IC23_11: U13.12 (Q4); also elsewhere on the board
LKB_2_13: LKB2.13; also elsewhere on the board
unnamed: LK3.1 (A), R23.1, U8.5 (I0b)
unnamed: LK4.1 (A), R24.1, U8.11 (I0d)
unnamed: LKB2.14, U6.12 (Q2)
unnamed: LKB2.15, LKB2.16, U6.13 (Q1)
unnamed: LKB2.17, U4.13, U6.14 (Q0)
unnamed: LKB2.18, U4.12
unnamed: LKB2.19, U4.6
unnamed: LKB2.20, U4.5, U4.10, U6.2 (CP)
unnamed: U3.8, U4.9, U7.6 (I1b)
unnamed: U13.15 (Q5), U18.11 (Clr)
unnamed: P4.1, U13.19 (Q7)
unnamed: U3.9, U18.2 (B), U18.5 (Q)
unnamed: C7.1, R29.2, U18.15 (RCext)
unnamed: U3.10, U18.4 (~Q)
unnamed: C6.1, R28.2, U18.7 (RCext)
PL1_8_INDEX: R14.1, U5.12 (I5); also elsewhere on the board
PL1_26_TRK_00: R13.1, U5.10 (I4); also elsewhere on the board
PL1_28_WP: R15.1, U5.14 (I6); also elsewhere on the board
TG43: LKB2.12, U5.7 (O3); also elsewhere on the board
VCC: R13.2, R14.2, R15.2, R16.2, R21.2, R22.1, R23.2, R24.2, R25.2, R26.1, R27.1, R28.1, R29.1, R30.2, U1.20 (VCC), U5.16 (VCC), U6.16 (VCC), U7.16 (VCC), U8.16 (VCC), U13.20 (VCC); also elsewhere on the board
~BRESET: U5.2 (I1); also elsewhere on the board

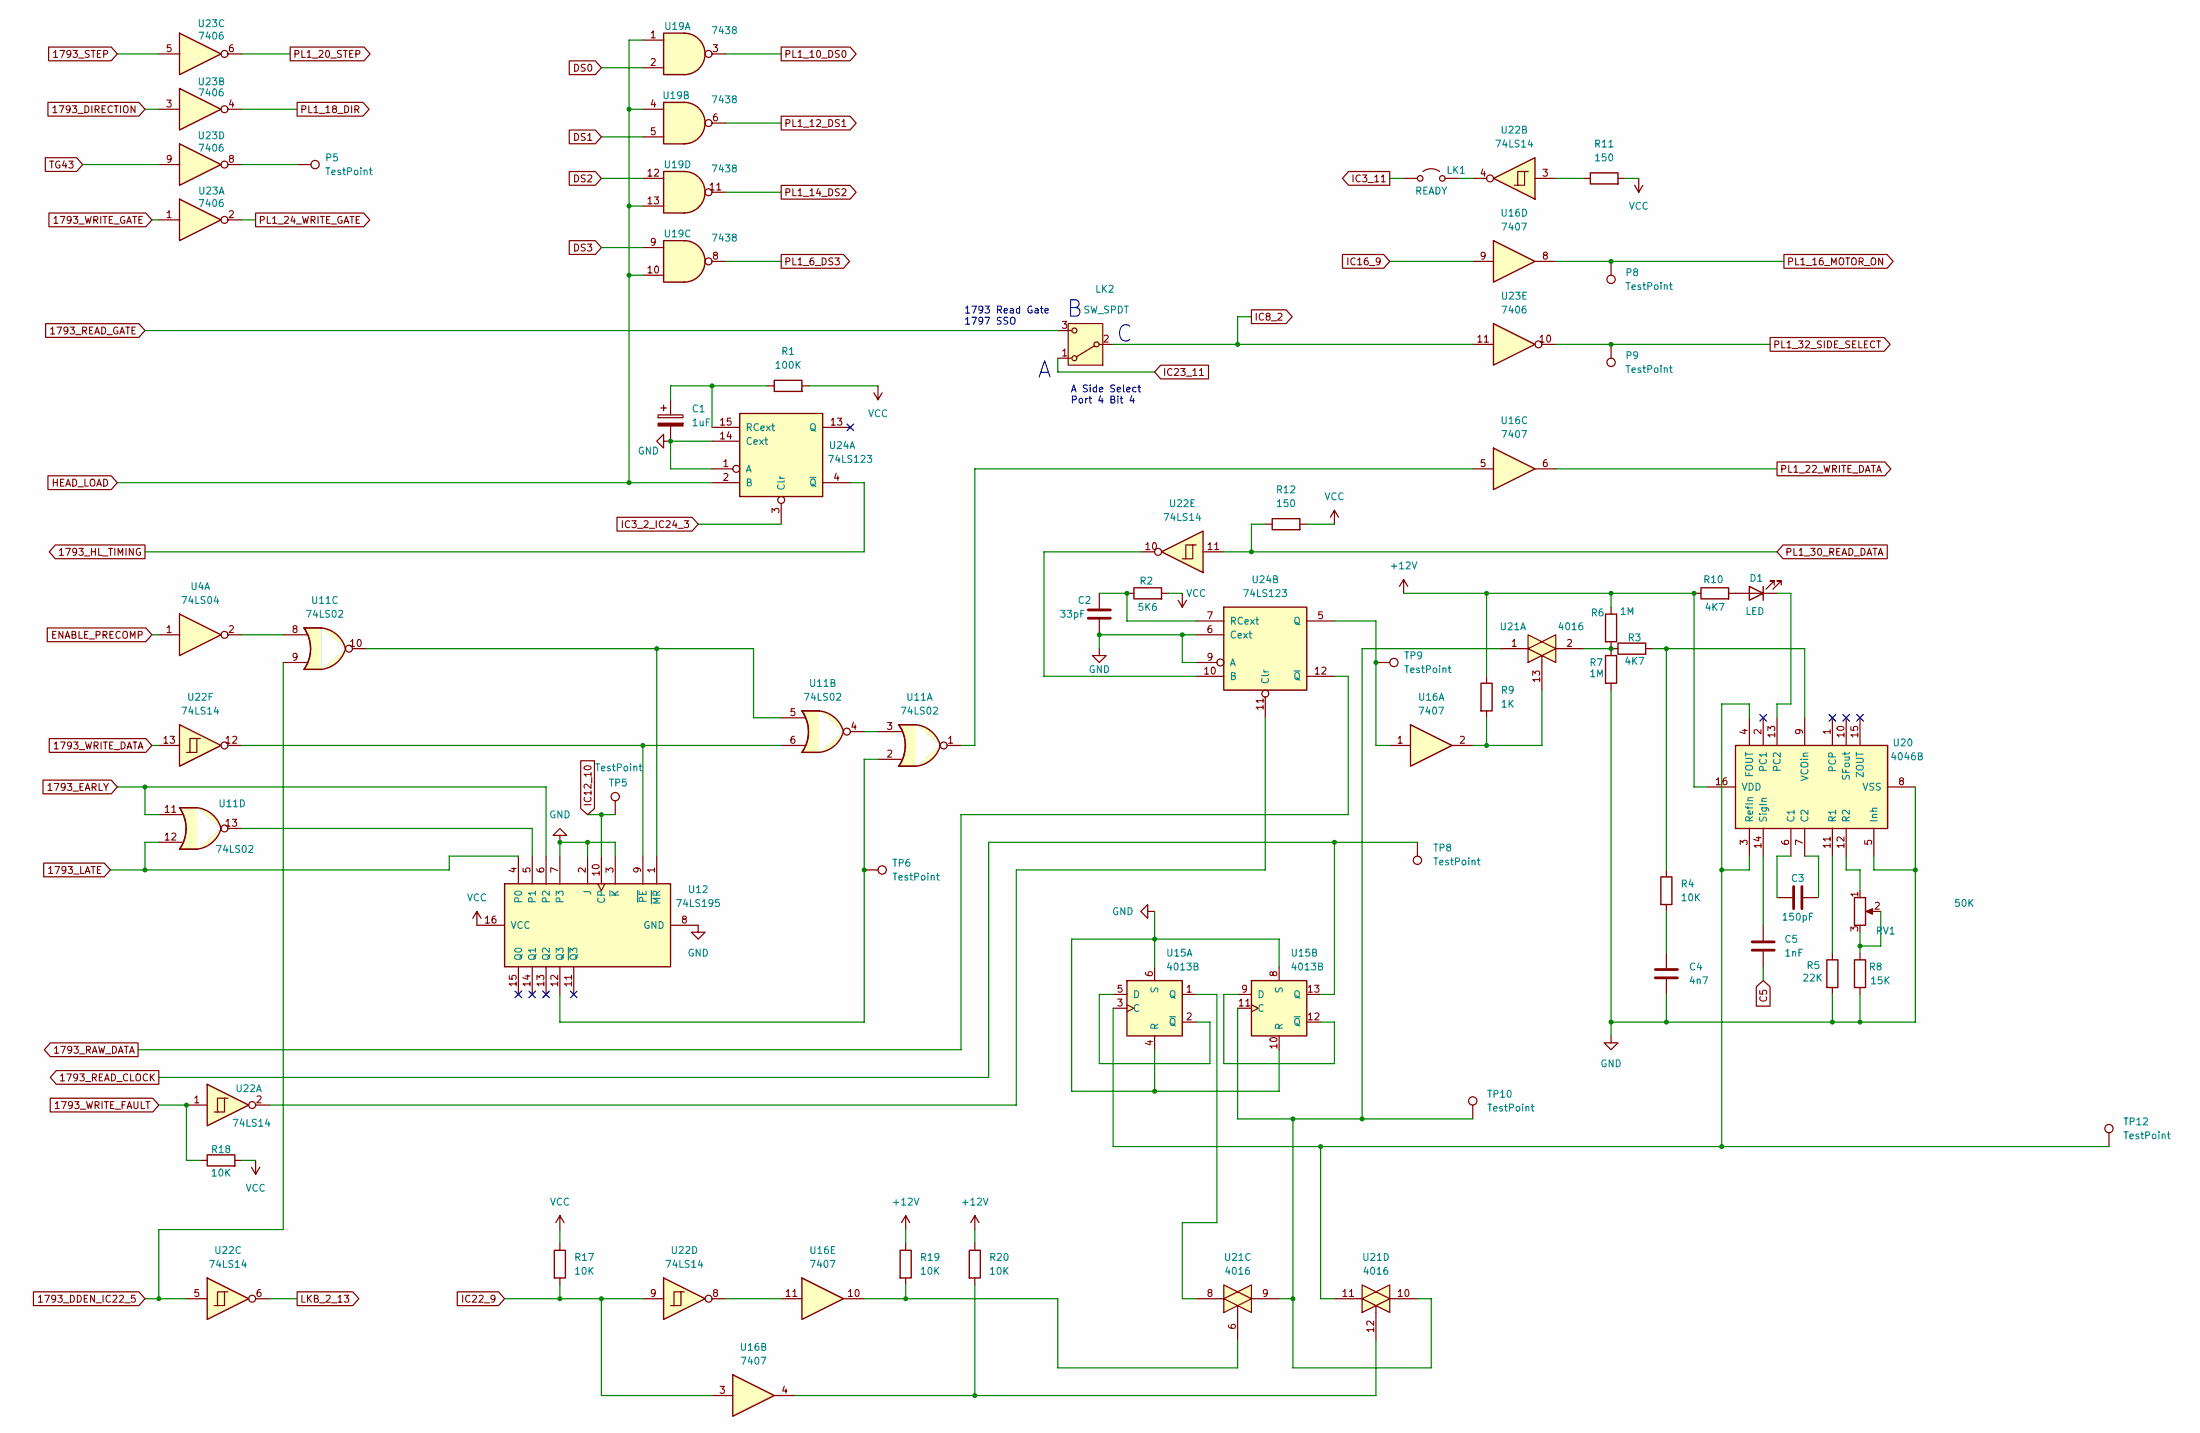
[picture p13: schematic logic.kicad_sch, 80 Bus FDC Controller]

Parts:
C1: 1uF; C_Disc_D6.0mm_W4.4mm_P5.00mm
C2: 33pF; C_Disc_D6.0mm_W4.4mm_P5.00mm
C3: 150pF; C_Disc_D6.0mm_W4.4mm_P5.00mm
C4: 4n7; C_Axial_L12.0mm_D6.5mm_P15.00mm_Horizontal
C5: 1nF; C_Disc_D6.0mm_W4.4mm_P5.00mm
D1: LED; LED_D3.0mm
LK1: READY; SW_DIP_SPSTx01_Slide_6.7x4.1mm_W7.62mm_P2.54mm_LowProfile
LK2: SW_SPDT; PinHeader_1x03_P2.54mm_Vertical
P5, P8, P9: TestPoint; TestPoint_THTPad_D1.5mm_Drill0.7mm
R1: 100K; R_Axial_DIN0309_L9.0mm_D3.2mm_P12.70mm_Horizontal
R2: 5K6; R_Axial_DIN0309_L9.0mm_D3.2mm_P12.70mm_Horizontal
R3, R10: 4K7; R_Axial_DIN0309_L9.0mm_D3.2mm_P12.70mm_Horizontal
R4, R17, R18, R19, R20: 10K; R_Axial_DIN0309_L9.0mm_D3.2mm_P12.70mm_Horizontal
R5: 22K; R_Axial_DIN0309_L9.0mm_D3.2mm_P12.70mm_Horizontal
R6, R7: 1M; R_Axial_DIN0309_L9.0mm_D3.2mm_P12.70mm_Horizontal
R8: 15K; R_Axial_DIN0309_L9.0mm_D3.2mm_P12.70mm_Horizontal
R9: 1K; R_Axial_DIN0309_L9.0mm_D3.2mm_P12.70mm_Horizontal
R11, R12: 150; R_Axial_DIN0309_L9.0mm_D3.2mm_P12.70mm_Horizontal
RV1: 50K; Potentiometer_Vishay_43_Horizontal
TP5, TP6, TP8, TP9, TP10, TP12: TestPoint; TestPoint_THTPad_D1.5mm_Drill0.7mm
U4: 74LS04; DIP-14_W7.62mm_Socket
U11: 74LS02; DIP-14_W7.62mm_Socket
U12: 74LS195; DIP-16_W7.62mm_Socket
U15: 4013B; DIP-14_W7.62mm_Socket
U16: 7407; DIP-14_W7.62mm_Socket
U19: 7438; DIP-14_W7.62mm_Socket
U20: 4046B; DIP-16_W7.62mm_Socket
U21: 4016; DIP-14_W7.62mm_Socket
U22: 74LS14; DIP-14_W7.62mm_Socket
U23: 7406; DIP-14_W7.62mm_Socket
U24: 74LS123; DIP-16_W7.62mm_Socket

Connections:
1793_DDEN_IC22_5: U11.9, U22.5; also elsewhere on the board
1793_DIRECTION: U23.3; also elsewhere on the board
1793_EARLY: U11.11, U12.6 (P2); also elsewhere on the board
1793_HL_TIMING: U24.4 (~Q); also elsewhere on the board
1793_LATE: U11.12, U12.4 (P0); also elsewhere on the board
1793_RAW_DATA: U24.12 (~Q); also elsewhere on the board
1793_READ_CLOCK: TP8.1, U15.13 (Q); also elsewhere on the board
1793_READ_GATE: LK2.3 (C); also elsewhere on the board
1793_STEP: U23.5; also elsewhere on the board
1793_WRITE_DATA: U22.13; also elsewhere on the board
1793_WRITE_FAULT: R18.1, U22.1; also elsewhere on the board
1793_WRITE_GATE: U23.1; also elsewhere on the board
+12V: R6.1, R9.1, R10.1, R19.1, R20.1, U20.16 (VDD); also elsewhere on the board
C5: C5.2; also elsewhere on the board
DS0: U19.2; also elsewhere on the board
DS1: U19.5; also elsewhere on the board
DS2: U19.12; also elsewhere on the board
DS3: U19.9; also elsewhere on the board
ENABLE_PRECOMP: U4.1; also elsewhere on the board
GND: C1.2, C2.2, C4.2, R5.2, R7.2, R8.2, U12.2 (J), U12.3 (~K), U12.7 (P3), U12.8 (GND), U15.4 (R), U15.6 (S), U15.8 (S), U15.10 (R), U20.5 (Inh), U20.8 (VSS), U24.1 (A), U24.6 (Cext), U24.9 (A), U24.14 (Cext); also elsewhere on the board
HEAD_LOAD: U19.1, U19.4, U19.10, U19.13, U24.2 (B); also elsewhere on the board
IC3_2_IC24_3: U24.3 (Clr); also elsewhere on the board
IC3_11: LK1.1 (A); also elsewhere on the board
IC8_2: LK2.2 (B), U23.11; also elsewhere on the board
IC12_10: TP5.1, U12.10 (CP); also elsewhere on the board
IC16_9: U16.9; also elsewhere on the board
IC22_9: R17.2, U16.3, U22.9; also elsewhere on the board
IC23_11: LK2.1 (A); also elsewhere on the board
LKB_2_13: U22.6; also elsewhere on the board
unnamed: C4.1, R4.2
unnamed: D1.2 (A), R10.2
unnamed: D1.1 (K), U20.13 (PC2)
unnamed: LK1.2 (B), U22.4
unnamed: P5.1, U23.8
unnamed: R3.1, R6.2, R7.1, U21.2
unnamed: R8.1, RV1.2, RV1.3
unnamed: R9.2, U16.2, U21.13
unnamed: R11.1, U22.3
unnamed: R19.2, U16.10, U21.6
unnamed: R20.2, U16.4, U21.12
unnamed: U11.1, U16.5
unnamed: U11.3, U11.4
unnamed: U4.2, U11.8
unnamed: U11.13, U12.5 (P1)
unnamed: TP6.1, U11.2, U12.12 (Q3)
unnamed: U11.5, U11.10, U12.1 (~MR)
unnamed: U11.6, U12.9 (~PE), U22.12
unnamed: TP12.1, U15.3 (C), U20.3 (RefIn), U20.4 (FOUT), U21.11
unnamed: U15.2 (~Q), U15.5 (D)
unnamed: U15.1 (Q), U21.8
unnamed: TP10.1, U15.11 (C), U21.1, U21.9, U21.10
unnamed: U15.9 (D), U15.12 (~Q)
unnamed: U16.11, U22.8
unnamed: C3.1, U20.6 (C1)
unnamed: C3.2, U20.7 (C2)
unnamed: R5.1, U20.11 (R1)
unnamed: RV1.1, U20.12 (R2)
unnamed: C5.1, U20.14 (SigIn)
unnamed: R3.2, R4.1, U20.9 (VCOin)
unnamed: C1.1, R1.1, U24.15 (RCext)
unnamed: U22.10, U24.10 (B)
unnamed: U22.2, U24.11 (Clr)
unnamed: TP9.1, U16.1, U24.5 (Q)
unnamed: C2.1, R2.1, U24.7 (RCext)
PL1_6_DS3: U19.8; also elsewhere on the board
PL1_10_DS0: U19.3; also elsewhere on the board
PL1_12_DS1: U19.6; also elsewhere on the board
PL1_14_DS2: U19.11; also elsewhere on the board
PL1_16_MOTOR_ON: P8.1, U16.8; also elsewhere on the board
PL1_18_DIR: U23.4; also elsewhere on the board
PL1_20_STEP: U23.6; also elsewhere on the board
PL1_22_WRITE_DATA: U16.6; also elsewhere on the board
PL1_24_WRITE_GATE: U23.2; also elsewhere on the board
PL1_30_READ_DATA: R12.1, U22.11; also elsewhere on the board
PL1_32_SIDE_SELECT: P9.1, U23.10; also elsewhere on the board
TG43: U23.9; also elsewhere on the board
VCC: R1.2, R2.2, R11.2, R12.2, R17.1, R18.2, U12.16 (VCC); also elsewhere on the board

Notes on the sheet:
1793 Read Gate 1797 SSO
A Side Select Port 4 Bit 4

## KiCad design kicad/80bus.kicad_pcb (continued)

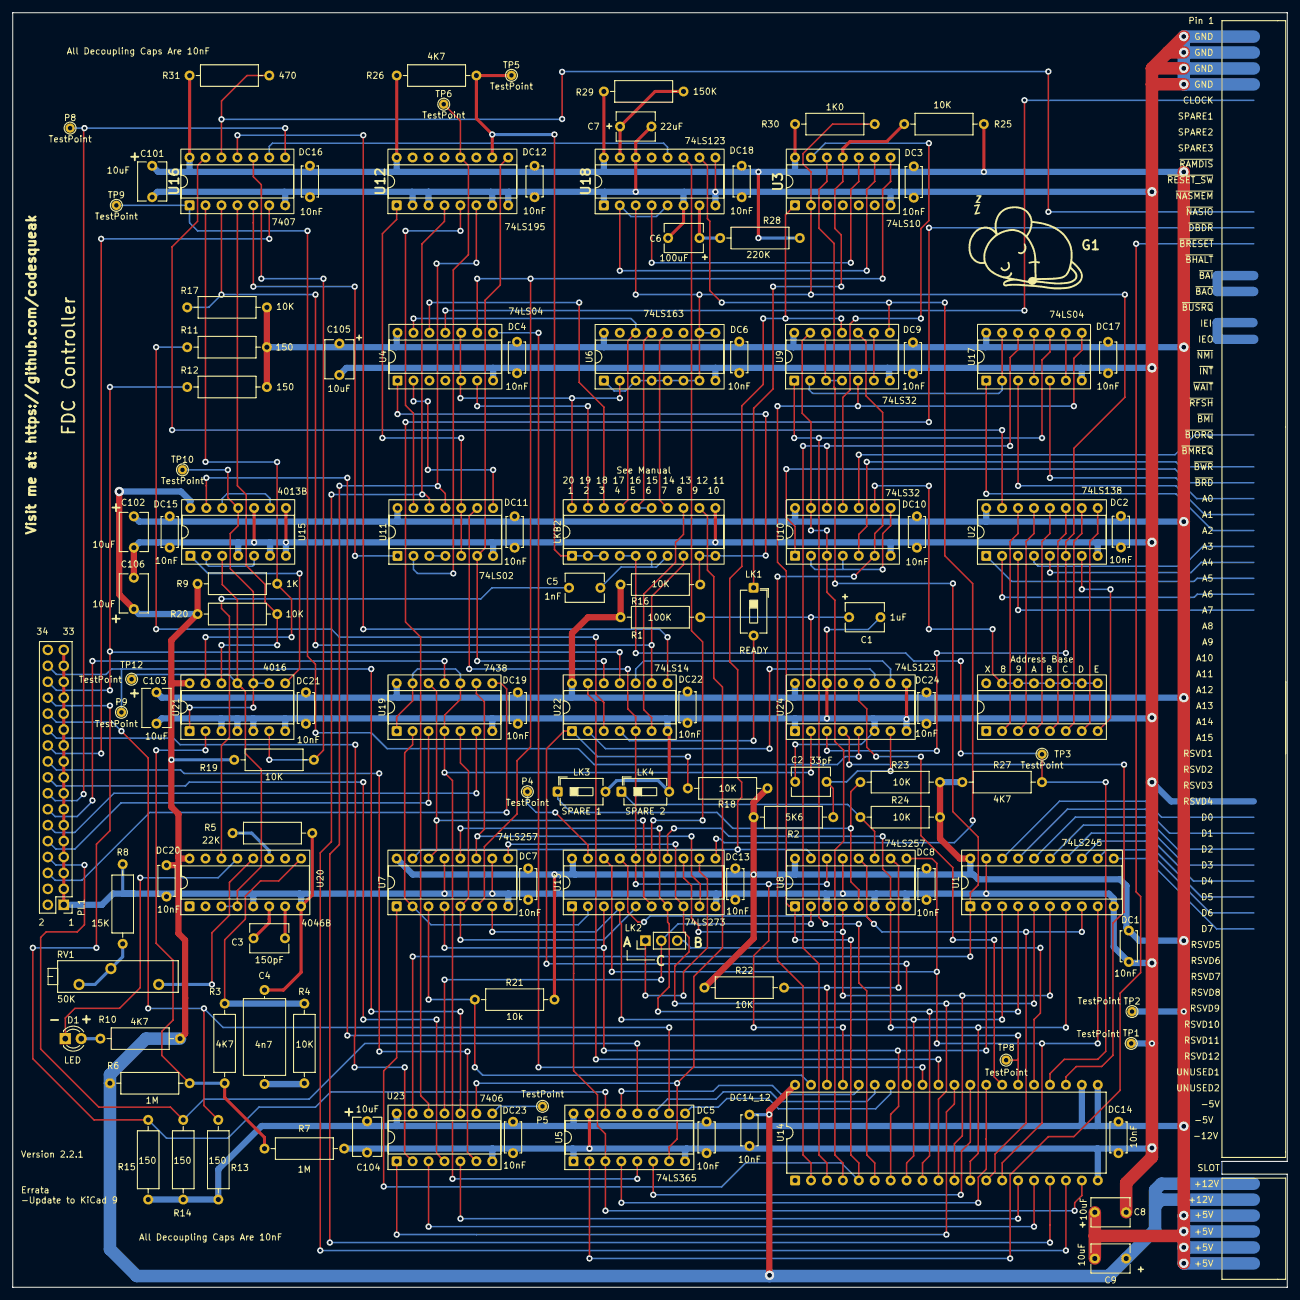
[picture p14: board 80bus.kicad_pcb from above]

Board: 2 copper layers, 203.2 x 203.2 mm, 120 parts (1 on the bottom side), 162 nets.

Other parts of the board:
G1: LOGO; sleepymouse_small
G001: LOGO; qr-code

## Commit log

2023-07-04 Initial file drop
    [80bus.kicad_pcb, 80bus.kicad_sch, 80bus.sch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]
2025-03-30 Document update / Kikad 9
    [80bus.kicad_pcb, 80bus.kicad_sch, address.kicad_sch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]
2025-04-06 Version update
    [80bus.kicad_pcb, 80bus.kicad_sch, address.kicad_sch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]
2025-04-16 Update docs
    [80bus.kicad_pcb, 80bus.kicad_sch, address.kicad_sch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]
